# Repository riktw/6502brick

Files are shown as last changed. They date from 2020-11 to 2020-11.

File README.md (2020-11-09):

# 6502brick
A 6502 dev board usable with multiple popular projects

This board features a 65C02 CPU, 32K RAM, 32K ROM (16K mapped by default), a 65C22 VIA and a MC6850 ACIA.
A 40 pin header is available with address, data and control signals to extend the board more, or to connect a logic analyzer.
Like Ben Eater's amazing video's, a button is available for single stepping.

The memory map and interrupts are controlled via GALs for flexibility

More information can be read here:  https://justanotherelectronicsblog.com/?p=802

# Memory map:

0x0000 - 0x7FFF		RAM

0x8000 - 0x9FFF		External peripherals

0xA000 - 0xAFFF		MC6850 ACIA for UART

0xB000 - 0xBFFF		65C22 VIA for GPIO + Timers

0xC000 - 0xFFFF		ROM

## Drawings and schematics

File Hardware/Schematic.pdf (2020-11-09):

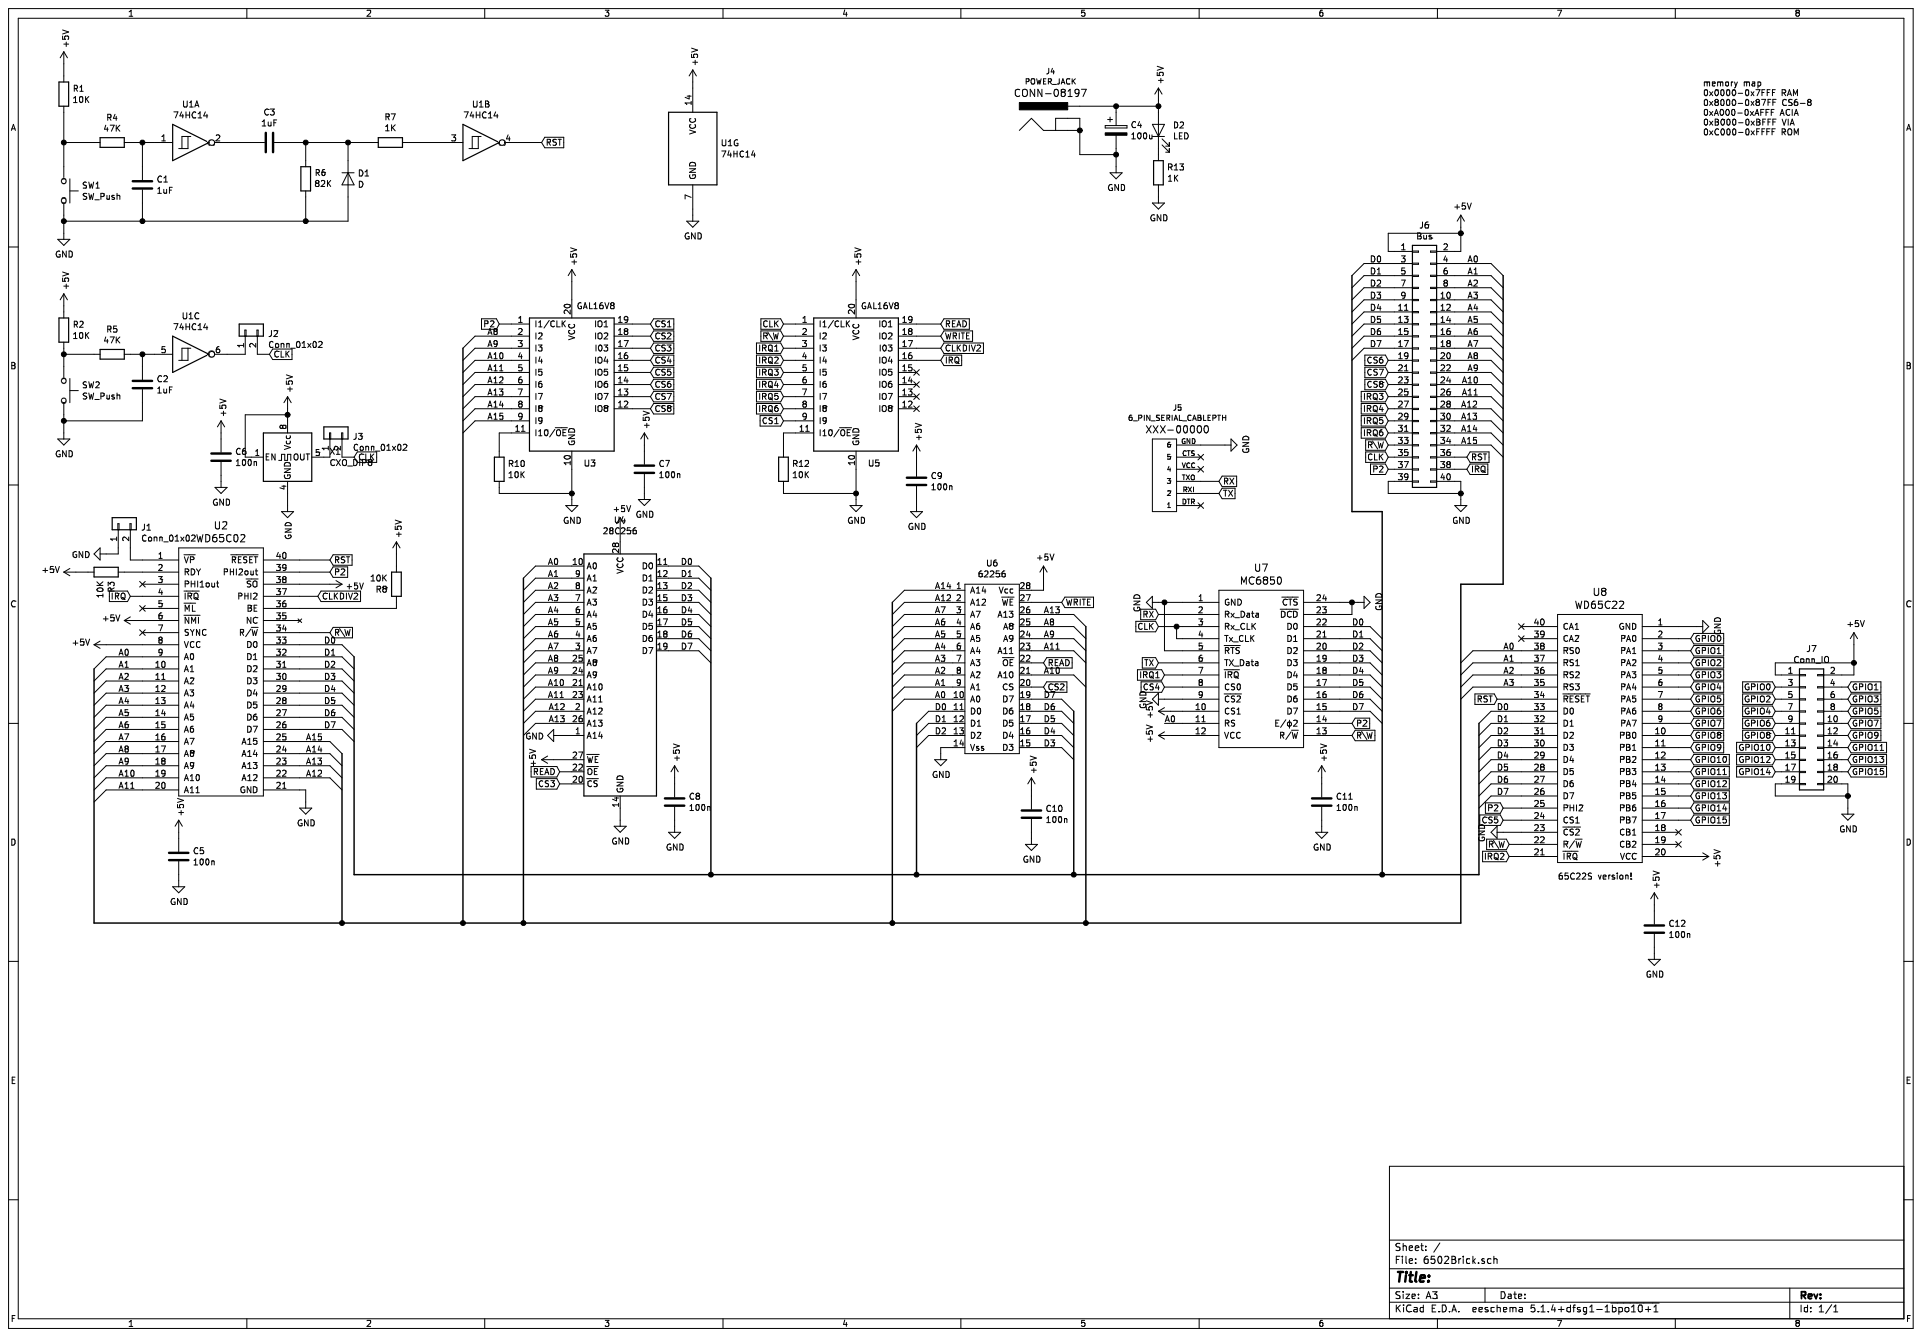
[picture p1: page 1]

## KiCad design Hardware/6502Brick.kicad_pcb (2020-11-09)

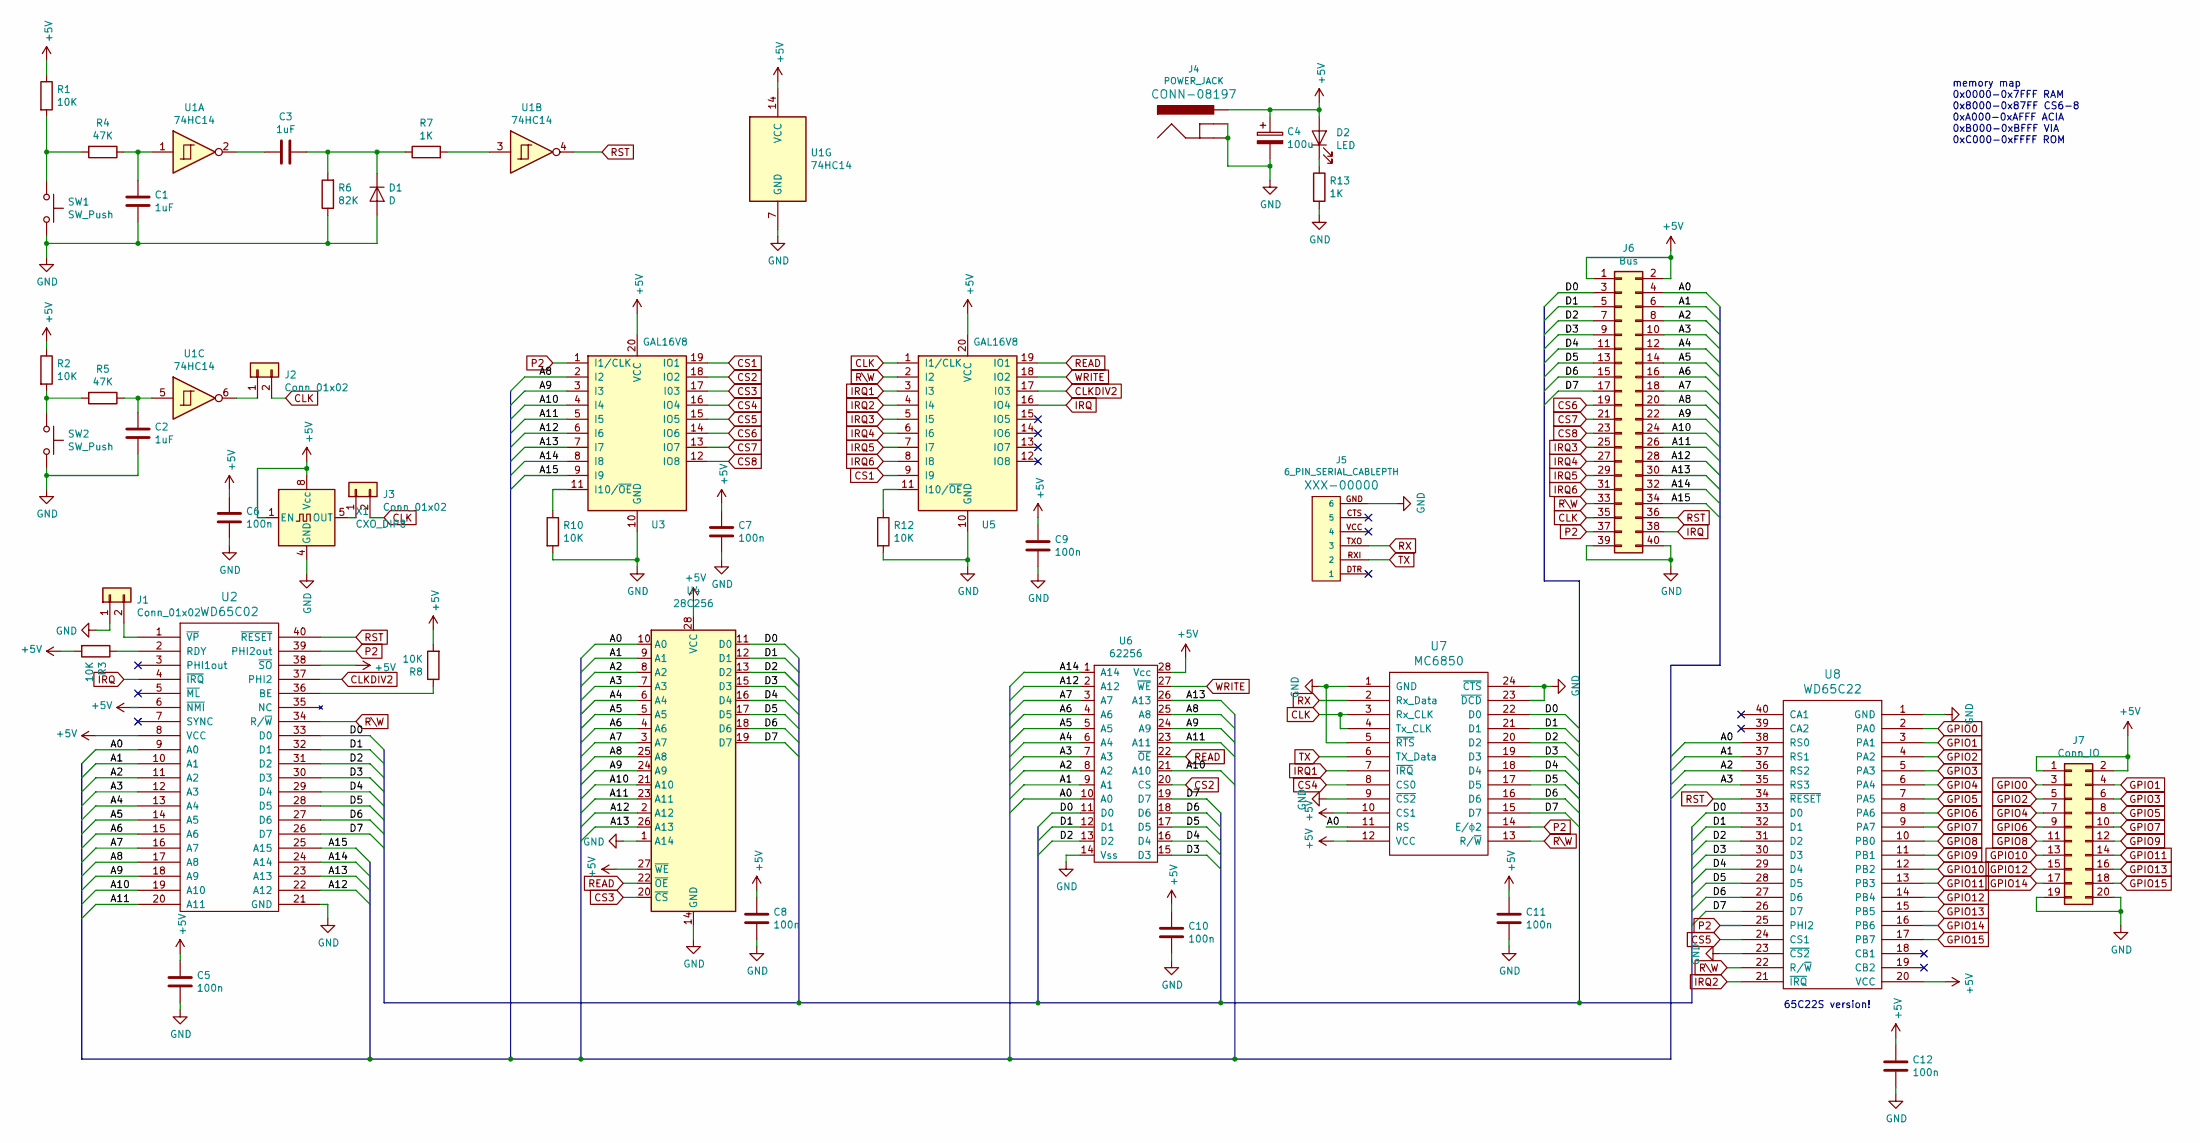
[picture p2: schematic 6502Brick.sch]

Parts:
C1, C2, C3: 1uF; C_Rect_L7.0mm_W2.5mm_P5.00mm
C4: 100u; CP_Radial_D5.0mm_P2.00mm
C5, C6, C7, C8, C9, C10, C11, C12: 100n; C_Rect_L7.0mm_W2.5mm_P5.00mm
D1: D; D_DO-34_SOD68_P7.62mm_Horizontal
D2: LED; LED_D5.0mm
J1, J2, J3: Conn_01x02; PinSocket_1x02_P2.54mm_Vertical
J4: POWER_JACK; POWER_JACK_PTH
J5: 6_PIN_SERIAL_CABLEPTH; FTDI_BASIC
J6: Bus; PinSocket_2x20_P2.54mm_Horizontal
J7: Conn_IO; IDC-Header_2x10_P2.54mm_Vertical
R1, R2, R3, R8, R10, R12: 10K; R_Axial_DIN0207_L6.3mm_D2.5mm_P2.54mm_Vertical
R4, R5: 47K; R_Axial_DIN0207_L6.3mm_D2.5mm_P2.54mm_Vertical
R6: 82K; R_Axial_DIN0207_L6.3mm_D2.5mm_P2.54mm_Vertical
R7, R13: 1K; R_Axial_DIN0207_L6.3mm_D2.5mm_P2.54mm_Vertical
SW1, SW2: SW_Push; SW_PUSH_6mm
U1: 74HC14; DIP-14_W7.62mm
U2: WD65C02; DIP-40_W15.24mm_Socket
U3, U5: GAL16V8; DIP-20_W7.62mm_Socket
U4: 28C256; DIP_Socket-28_W11.9_W12.7_W15.24_W17.78_W18.5_3M_228-1277-0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
U6: 62256; DIP-28_W15.24mm_Socket
U7: MC6850; DIP-24_W15.24mm_Socket
U8: WD65C22; DIP-40_W15.24mm_Socket
X1: CXO_DIP8; Oscillator_DIP-8

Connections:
+5V: C4.1, C5.1, C6.1, C7.1, C8.1, C9.1, C10.1, C11.1, C12.1, D2.2 (A), J4.PWR, J6.1, J6.2, J7.1, J7.2, R1.1, R2.1, R3.2, R8.2, U1.14 (VCC), U2.6 (~NMI), U2.8 (VCC), U2.38 (~SO), U3.20 (VCC), U4.27 (~WE), U4.28 (VCC), U5.20 (VCC), U6.28 (Vcc), U7.10 (CS1), U7.12 (VCC), U8.20 (VCC), X1.1 (EN), X1.8 (Vcc)
/A0: J6.4, U2.9 (A0), U4.10 (A0), U6.10 (A0), U7.11 (RS), U8.38 (RS0)
/A1: J6.6, U2.10 (A1), U4.9 (A1), U6.9 (A1), U8.37 (RS1)
/A2: J6.8, U2.11 (A2), U4.8 (A2), U6.8 (A2), U8.36 (RS2)
/A3: J6.10, U2.12 (A3), U4.7 (A3), U6.7 (A3), U8.35 (RS3)
/A4: J6.12, U2.13 (A4), U4.6 (A4), U6.6 (A4)
/A5: J6.14, U2.14 (A5), U4.5 (A5), U6.5 (A5)
/A6: J6.16, U2.15 (A6), U4.4 (A6), U6.4 (A6)
/A7: J6.18, U2.16 (A7), U4.3 (A7), U6.3 (A7)
/A8: J6.20, U2.17 (A8), U3.2 (I2), U4.25 (A8), U6.25 (A8)
/A9: J6.22, U2.18 (A9), U3.3 (I3), U4.24 (A9), U6.24 (A9)
/A10: J6.24, U2.19 (A10), U3.4 (I4), U4.21 (A10), U6.21 (A10)
/A11: J6.26, U2.20 (A11), U3.5 (I5), U4.23 (A11), U6.23 (A11)
/A12: J6.28, U2.22 (A12), U3.6 (I6), U4.2 (A12), U6.2 (A12)
/A13: J6.30, U2.23 (A13), U3.7 (I7), U4.26 (A13), U6.26 (A13)
/A14: J6.32, U2.24 (A14), U3.8 (I8), U6.1 (A14)
/A15: J6.34, U2.25 (A15), U3.9 (I9)
/D0: J6.3, U2.33 (D0), U4.11 (D0), U6.11 (D0), U7.22 (D0), U8.33 (D0)
/D1: J6.5, U2.32 (D1), U4.12 (D1), U6.12 (D1), U7.21 (D1), U8.32 (D1)
/D2: J6.7, U2.31 (D2), U4.13 (D2), U6.13 (D2), U7.20 (D2), U8.31 (D2)
/D3: J6.9, U2.30 (D3), U4.15 (D3), U6.15 (D3), U7.19 (D3), U8.30 (D3)
/D4: J6.11, U2.29 (D4), U4.16 (D4), U6.16 (D4), U7.18 (D4), U8.29 (D4)
/D5: J6.13, U2.28 (D5), U4.17 (D5), U6.17 (D5), U7.17 (D5), U8.28 (D5)
/D6: J6.15, U2.27 (D6), U4.18 (D6), U6.18 (D6), U7.16 (D6), U8.27 (D6)
/D7: J6.17, U2.26 (D7), U4.19 (D7), U6.19 (D7), U7.15 (D7), U8.26 (D7)
CLK: J2.2, J3.2, J6.35, U5.1 (I1/CLK), U7.3 (Rx_CLK), U7.4 (Tx_CLK)
CLKDIV2: U2.37 (PHI2), U5.17 (I03)
CS1: U3.19 (IO1), U5.9 (I9)
CS2: U3.18 (IO2), U6.20 (CS)
CS3: U3.17 (I03), U4.20 (~CS)
CS4: U3.16 (IO4), U7.8 (CS0)
CS5: U3.15 (IO5), U8.24 (CS1)
CS6: J6.19, U3.14 (IO6)
CS7: J6.21, U3.13 (IO7)
CS8: J6.23, U3.12 (IO8)
GND: C1.2, C2.2, C4.2, C5.2, C6.2, C7.2, C8.2, C9.2, C10.2, C11.2, C12.2, D1.2 (A), J1.1, J4.GND, J4.GNDB (GNDBREAK), J5.GND (6), J6.39, J6.40, J7.19, J7.20, R6.1, R10.2, R12.2, R13.2, SW1.2, SW2.2, U1.7 (GND), U2.21 (GND), U3.10 (GND), U4.1 (A14), U4.14 (GND), U5.10 (GND), U6.14 (Vss), U7.1 (GND), U7.5 (~RTS), U7.9 (~CS2), U7.23 (~DCD), U7.24 (~CTS), U8.1 (GND), U8.23 (~CS2), X1.4 (GND)
GPIO0: J7.3, U8.2 (PA0)
GPIO1: J7.4, U8.3 (PA1)
GPIO2: J7.5, U8.4 (PA2)
GPIO3: J7.6, U8.5 (PA3)
GPIO4: J7.7, U8.6 (PA4)
GPIO5: J7.8, U8.7 (PA5)
GPIO6: J7.9, U8.8 (PA6)
GPIO7: J7.10, U8.9 (PA7)
GPIO8: J7.11, U8.10 (PB0)
GPIO9: J7.12, U8.11 (PB1)
GPIO10: J7.13, U8.12 (PB2)
GPIO11: J7.14, U8.13 (PB3)
GPIO12: J7.15, U8.14 (PB4)
GPIO13: J7.16, U8.15 (PB5)
GPIO14: J7.17, U8.16 (PB6)
GPIO15: J7.18, U8.17 (PB7)
IRQ: J6.38, U2.4 (~IRQ), U5.16 (IO4)
IRQ1: U5.3 (I3), U7.7 (~IRQ)
IRQ2: U5.4 (I4), U8.21 (~IRQ)
IRQ3: J6.25, U5.5 (I5)
IRQ4: J6.27, U5.6 (I6)
IRQ5: J6.29, U5.7 (I7)
IRQ6: J6.31, U5.8 (I8)
unnamed: C1.1, R4.1, U1.1
unnamed: C2.1, R5.1, U1.5
unnamed: C3.1, D1.1 (K), R6.2, R7.1
unnamed: C3.2, U1.2
unnamed: D2.1 (K), R13.1
unnamed: J1.2, U2.1 (~VP)
unnamed: J2.1, U1.6
unnamed: J3.1, X1.5 (OUT)
unnamed: R1.2, R4.2, SW1.1
unnamed: R2.2, R5.2, SW2.1
unnamed: R3.1, U2.2 (RDY)
unnamed: R7.2, U1.3
unnamed: R8.1, U2.36 (BE)
unnamed: R10.1, U3.11 (I10/~OE~)
unnamed: R12.1, U5.11 (I10/~OE~)
P2: J6.37, U2.39 (PHI2out), U3.1 (I1/CLK), U7.14 (E/ϕ2), U8.25 (PHI2)
READ: U4.22 (~OE), U5.19 (IO1), U6.22 (~OE)
RST: J6.36, U1.4, U2.40 (~RESET), U8.34 (~RESET)
RX: J5.TXO (3), U7.2 (Rx_Data)
R\W: J6.33, U2.34 (R/~W), U5.2 (I2), U7.13 (R/~W), U8.22 (R/~W)
TX: J5.RXI (2), U7.6 (TX_Data)
WRITE: U5.18 (IO2), U6.27 (~WE)

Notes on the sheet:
65C22S version!
memory map 0x0000-0x7FFF RAM 0x8000-0x87FF CS6-8 0xA000-0xAFFF ACIA 0xB000-0xBFFF VIA 0xC000-0xFFFF ROM

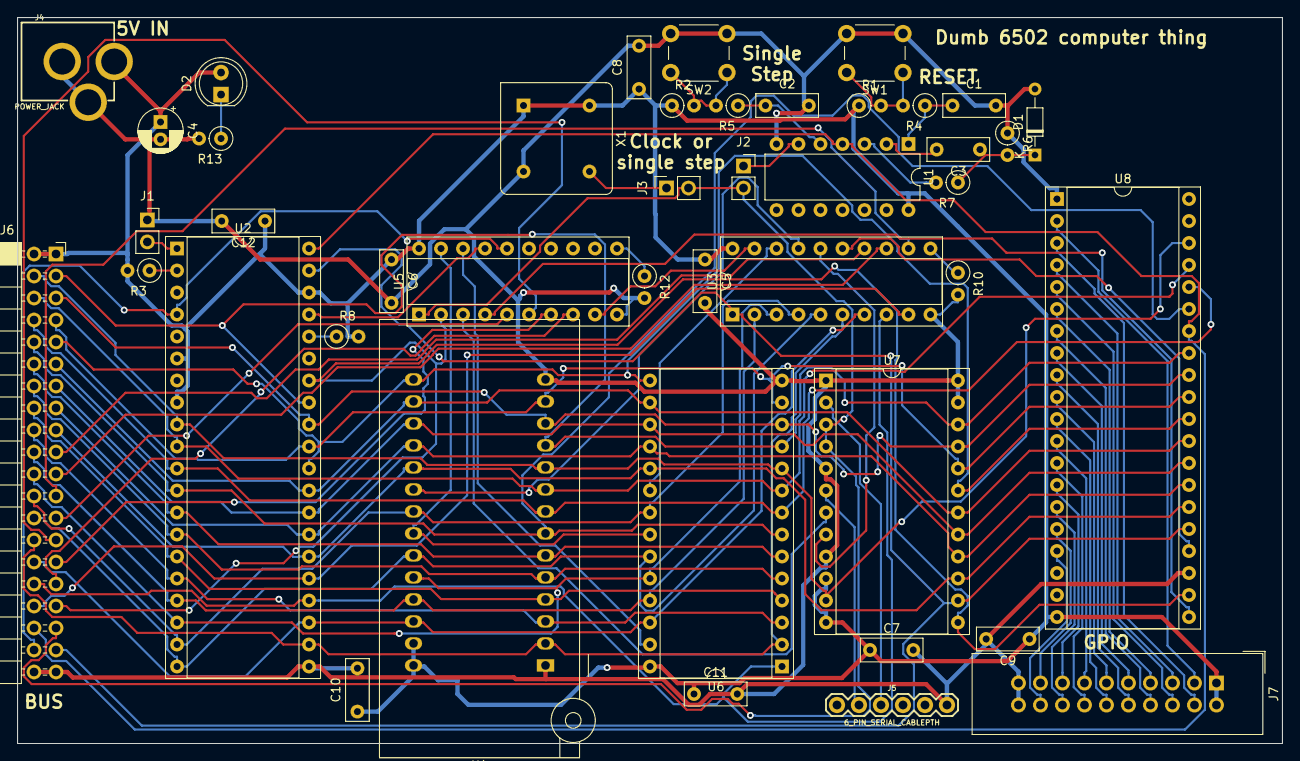
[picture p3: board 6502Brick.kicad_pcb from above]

Board: 2 copper layers, 146.0 x 83.8 mm, 43 parts (0 on the bottom side), 81 nets.

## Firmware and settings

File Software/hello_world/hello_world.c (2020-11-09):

#pragma link("linker.ld")

#include <stdint.h>
#include <stdio.h>

typedef struct 
{
  volatile uint8_t PortB;
  volatile uint8_t PortA;
  volatile uint8_t DirectionB;
  volatile uint8_t DirectionA;
  volatile uint8_t Timer1CounterLow;
  volatile uint8_t Timer1CounterHigh;
  volatile uint8_t Timer1LatchLow;
  volatile uint8_t Timer1LatchHigh;
  volatile uint8_t Timer2Latches;
  volatile uint8_t Timer2Counter;
  volatile uint8_t ShiftControl;
  volatile uint8_t TimerControl;
  volatile uint8_t Handshake;
  volatile uint8_t InterruptFlag;
  volatile uint8_t InterruptEnable;
} via_reg;    //VIA register mapping

typedef struct
{
  volatile uint8_t ControlStatus;
  volatile uint8_t ReceiveTransmit;
} acia_reg;   //UART ACIA register mapping


volatile uint16_t counter;
volatile via_reg* VIA1 = ((via_reg*)0xB000);    //VIA mapped to 0xB000
volatile acia_reg* ACIA1 = ((acia_reg*)0xA000); //ACIA UART mapped to 0xA000

#define LCD_E_PIN   0x80
#define LCD_RW_PIN  0x40
#define LCD_RS_PIN  0x20
#define LCD_NO_PINS 0x00

void sendCharacter(char payload) {
  //first check if transmit buffer is empty before filling it
  uint8_t status = ACIA1->ControlStatus;
  while(!(status & 0x02)) {     
    status = ACIA1->ControlStatus;
  };
  
  ACIA1->ReceiveTransmit = payload; 
}

void WaitForScreen() {
  // to chec if screen is ready for a new command, status has to be read.
  VIA1->DirectionB  = 0x00;     //PORTB input to read data
  
  while(1) {
    VIA1->PortA = LCD_RW_PIN;       //RW high to read data 
    VIA1->PortA = LCD_E_PIN | LCD_RW_PIN;  //Set E to Read status reg   
    uint8_t status = VIA1->PortB;
    uint8_t flag = (status & 0x80); //Check if bit 7 is high, indicating busy
    if(flag == 0x80) {
    }
    else {
      break;
    }
  }
  VIA1->PortA = LCD_RW_PIN;     //Clear E pin
  VIA1->DirectionB  = 0xFF;     //PORTB ouput again, done with reads
}

void ScreenSendInstruction(uint8_t instruction) {
  WaitForScreen();
  
  VIA1->PortB  = instruction;  
  VIA1->PortA = LCD_NO_PINS;   //RW and RS low, send instruction
  VIA1->PortA = LCD_E_PIN;     //Set E to send instruction
  VIA1->PortA = LCD_NO_PINS;   //Clear E pin
}

void ScreenPrintChar(char charToPrint) {
  WaitForScreen();
  
  VIA1->PortB  = charToPrint; 
  VIA1->PortA = LCD_RS_PIN;               //set rs pin to write character
  VIA1->PortA = LCD_E_PIN | LCD_RS_PIN;   //Set E to send instruction
  VIA1->PortA = LCD_RS_PIN;               //clear E pin
}

void main() {
    
    ACIA1->ControlStatus = 0x03;    //reset
    
    VIA1->DirectionB  = 0xFF;     //8 bit databus to display
    VIA1->DirectionA  = 0xE0;     //upper 3 pins for RS, RW, E pin of screen
    
    ScreenSendInstruction(0x38);  //8 bit mode, 2 line, 5x8 font 
    ScreenSendInstruction(0x0F);  //display on, cursor on, blink on
    ScreenSendInstruction(0x06);  //increment cursor, don't shift display
    ScreenSendInstruction(0x02);  //cursor to start
    ScreenSendInstruction(0x01);  //clear dislay
    
    uint8_t hello[] = "Hello world!"z;    //z means string without 0 termination
    for(uint8_t i = 0; i < sizeof(hello); ++i) {
      ScreenPrintChar(hello[i]);
    }
    
  
    ACIA1->ControlStatus = 0x15;    //divide clock by 16, 8 bit, 1 stop bit
    for(uint8_t i = 0; i < sizeof(hello); ++i) {
      sendCharacter(hello[i]);
    }

    while(1) { }
}

//no interrupts used here.
#pragma code_seg(IRQ)
interrupt(hardware_stack) void IRQ() {
}

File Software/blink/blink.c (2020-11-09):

#pragma link("linker.ld")     //use linker.ld file in the same folder

#include <stdint.h>
#include <stdio.h>

typedef struct 
{
  volatile uint8_t PortB;
  volatile uint8_t PortA;
  volatile uint8_t DirectionB;
  volatile uint8_t DirectionA;
  volatile uint8_t Timer1CounterLow;
  volatile uint8_t Timer1CounterHigh;
  volatile uint8_t Timer1LatchLow;
  volatile uint8_t Timer1LatchHigh;
  volatile uint8_t Timer2Latches;
  volatile uint8_t Timer2Counter;
  volatile uint8_t ShiftControl;
  volatile uint8_t TimerControl;
  volatile uint8_t Handshake;
  volatile uint8_t InterruptFlag;
  volatile uint8_t InterruptEnable;
} via_reg;    //VIA register mapping


volatile uint16_t counter;  //Need to define shared variable here, used in main and IRQ code
volatile via_reg* VIA1 = ((via_reg*)0xB000);    //VIA mapped to 0xB000


void main() {
  
    VIA1->DirectionB  = 0xFF;         //All IO on port B as output
    
    VIA1->TimerControl = 0x40;        //Continous mode
    VIA1->InterruptEnable = 0xC0;     //Timer 1 irq on
    
    VIA1->Timer1CounterHigh = 0x07;   //0x708, 1800, 1.8Mhz clk, 1ms irq
    VIA1->Timer1CounterLow = 0x08;    
       
    
    counter = 0;
    asm { cli }                       //Enable interrupts
    
    while(1) {
    }
}


#pragma code_seg(IRQ)     //Indicate to compiler that this cose has to go to IRQ section.

interrupt(hardware_stack) void IRQ() {
  
  counter++;
  if(counter < 500) {
    VIA1->PortB  = 0xFF;    //All LEDs on
  }
  else {
    VIA1->PortB  = 0x00;    //All LEDs off
  }
  if(counter >= 1000) {
    counter = 0;
  }
  VIA1->Timer1LatchHigh = 0x07;   //Writing to the LatchHigh resets the IRQ
}
